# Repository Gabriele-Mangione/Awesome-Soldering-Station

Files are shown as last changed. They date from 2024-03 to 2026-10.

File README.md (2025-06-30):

# ✨ Awesome Soldering Station ✨

---

## Project Overview 💡

This project introduces an **open-source DIY soldering station** featuring **USB-C Power Delivery** and an intuitive **touchscreen interface**. The goal is to provide a very affordable, highly functional, modifiable, and robust soldering solution built with modern embedded technologies for the DIY community!



A key design feature is its compatibility with **jack connector soldering tips**, specifically those used by Weller soldering stations, ensuring broad tip availability and performance.

While the primary development is focused on the **Rust** codebase for the latest iteration, a fully functional C++ version exists on the `2.0` branch, serving as a tested foundation.

---

## Technical Architecture ⚙️

The station's intelligence is distributed across two microcontrollers:

* **ESP32-S3 (Station Mainboard):** This microcontroller drives the core functionality of the station. It's programmed in **Rust** utilizing the `esp-hal` open-source framework. Firmware updates are streamlined and accessible, allowing for easy modification and programming directly through the **USB-C port** used for power delivery.

* **ATtiny24 (Soldering Handle):** A compact microcontroller embedded within the soldering handle, responsible for precise temperature sensing and control. It's programmed in **C++** within the Arduino environment and uploaded via an external ISP.

---

## Hardware Design & Construction 🛠️

The hardware is meticulously designed in **Altium Designer** and comprises two distinct printed circuit boards:

* **Station Mainboard:** This board houses the ESP32-S3, power delivery circuitry, display interface, and other essential components for the station's operation.


* **Soldering Handle Board:** A compact PCB designed to fit within the handle, facilitating sensor integration and handle-specific controls, crucial for the jack connector tips.


These two boards are interconnected by a cable, chosen for both its both comfort and flexibility during use, while ensuring reliable high-current power transmission without impedance issues. (I tested a lot of different ones)

The enclosure for the main station and the handle itself are both **3D printed**. This approach allows for a custom, ergonomic design and simplifies prototyping and production.
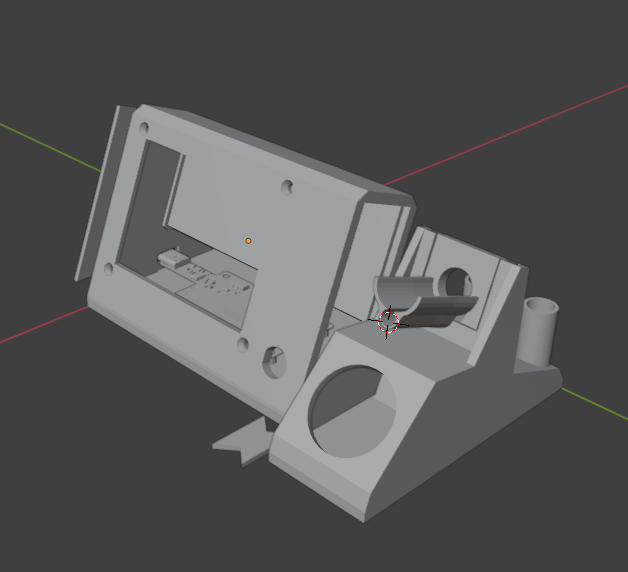
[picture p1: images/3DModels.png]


## Development Status & Technologies Used 💻

* **Hardware Design:** Altium Designer
* **Station Firmware:** Embedded Rust with `esp-hal` (active development branch)
* **Handle Firmware:** C++ using the Arduino environment
* **Case & Handle:** 3D Printed, designed with Blender
* **Tip Compatibility:** Designed for **Weller jack connector soldering tips**

---

## Getting Started (Prerequisites) 📝

#### For the Hardware:
If you take the DIY route:
* Order PCBs from your favourite PCB manufacturer (I use AISLER and JLCPCB)
* Order Parts from my Digi-Key Lists:
    * Handle: https://www.digikey.ch/en/mylists/list/VL3OIYCQ1Z
    * Station: https://www.digikey.ch/en/mylists/list/MW1GWRHM6E
* 3D print the files in the 3D-Models Folder
* Solder and mount everything together!

If you don't have the needed tools, you can opt to buy the finished product directly from me.
If so, feel free to contact me at Gabriele.Mangione@hotmail.com
#### For ESP32-S3 Firmware (Rust):
* **`esp-hal` Toolchain:** Refer to [https://docs.esp-rs.org/book/](https://docs.esp-rs.org/book/) for detailed setup instructions.
    * **Note:** For Windows users, Rust must be installed via `rustup` for compatibility.

* TODO: insert libs

#### For ATtiny24 Firmware (C++):
* **Arduino IDE** or **Arduino CLI**
* Appropriate ATtiny24 board definitions for the Arduino environment.

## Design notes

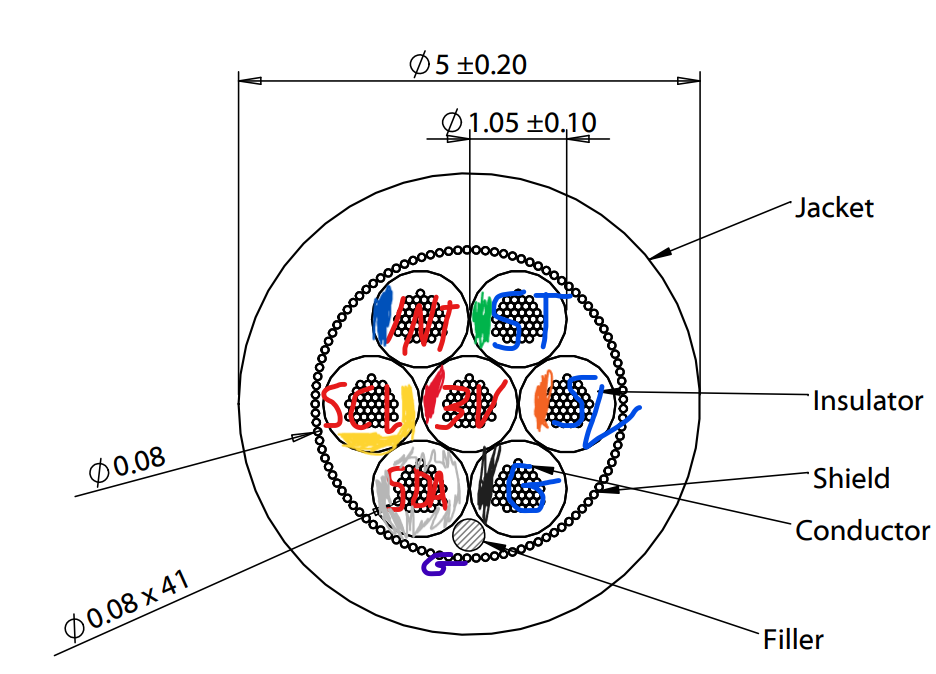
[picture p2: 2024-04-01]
cableorder.png

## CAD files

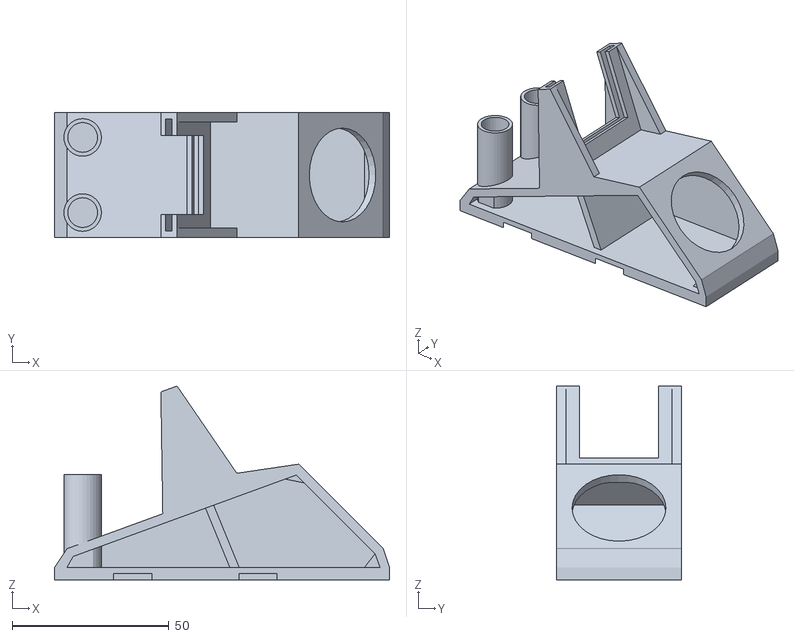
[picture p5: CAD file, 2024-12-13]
3D-Models/Case/iron_holder.stl
107.0 x 40.0 x 62.0

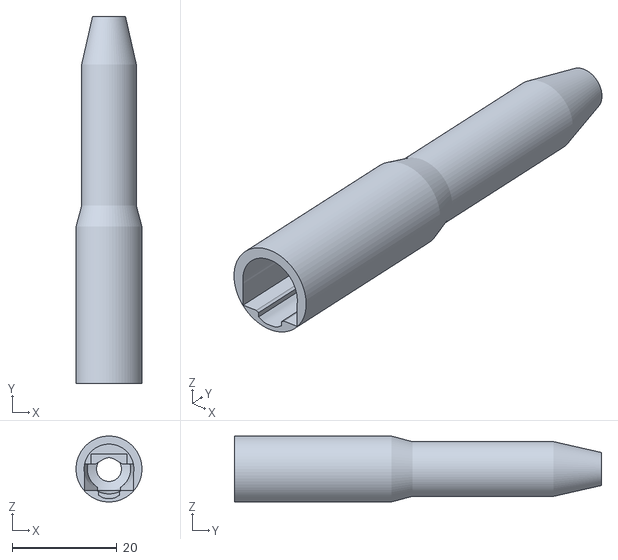
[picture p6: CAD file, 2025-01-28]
3D-Models/Iron-Pen/Iron-pen5.8.stl
12.6 x 70.1 x 12.6

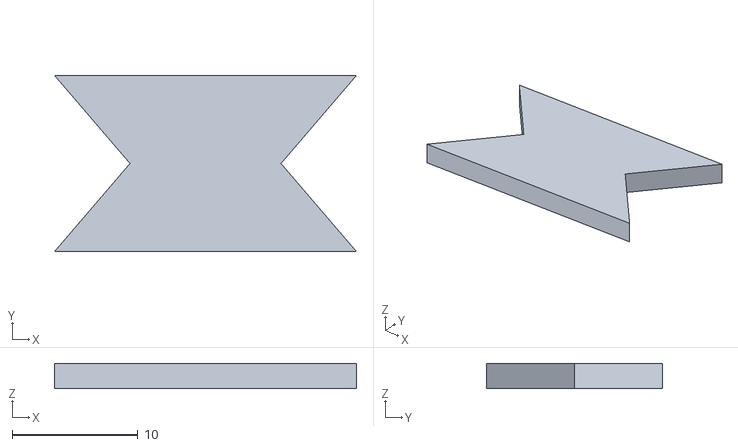
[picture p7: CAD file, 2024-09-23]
3D-Models/Case/connector.stl
24.0 x 14.0 x 2.00

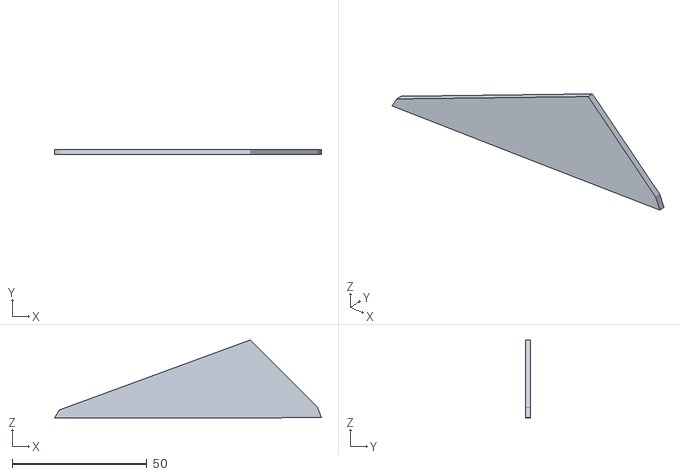
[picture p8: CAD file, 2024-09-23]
3D-Models/Case/iron_holder_wall.stl
98.9 x 2.00 x 28.9

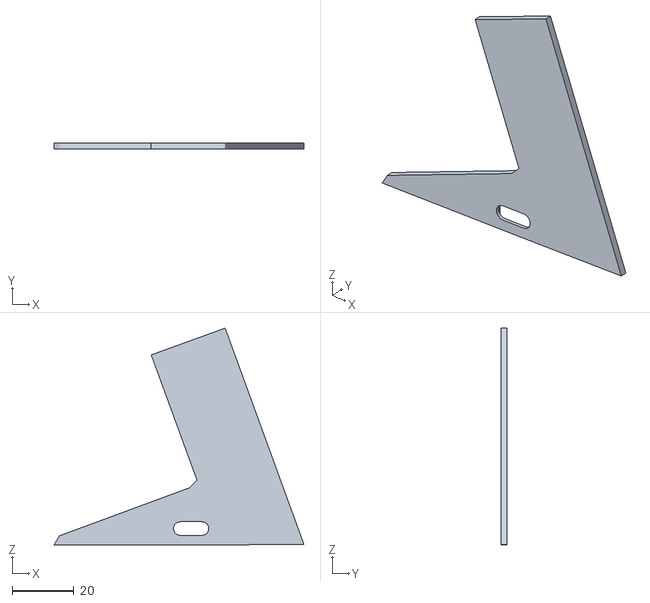
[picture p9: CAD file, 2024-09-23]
3D-Models/Case/usbc_wall.stl
80.9 x 2.00 x 70.2

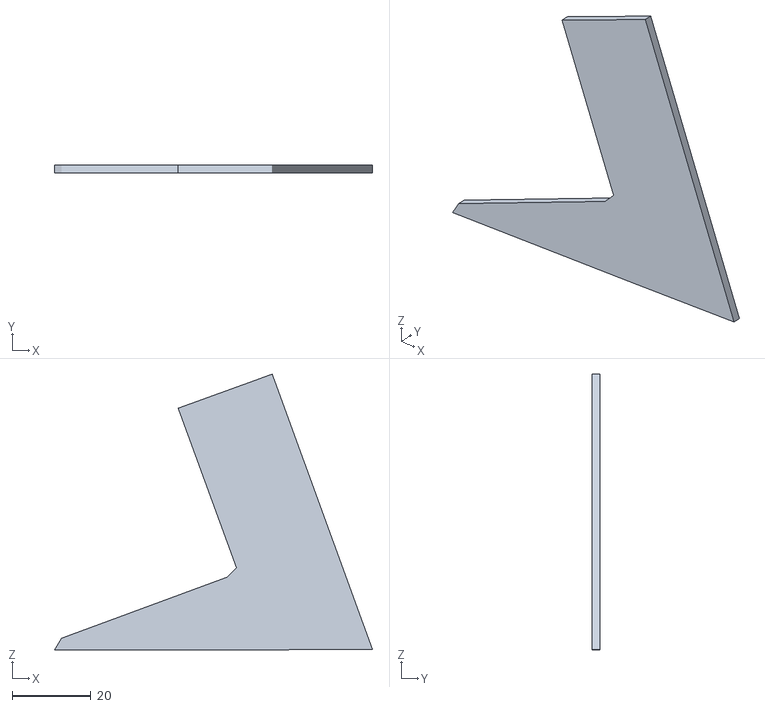
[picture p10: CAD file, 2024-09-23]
3D-Models/Case/normal_wall.stl
80.9 x 2.00 x 70.2

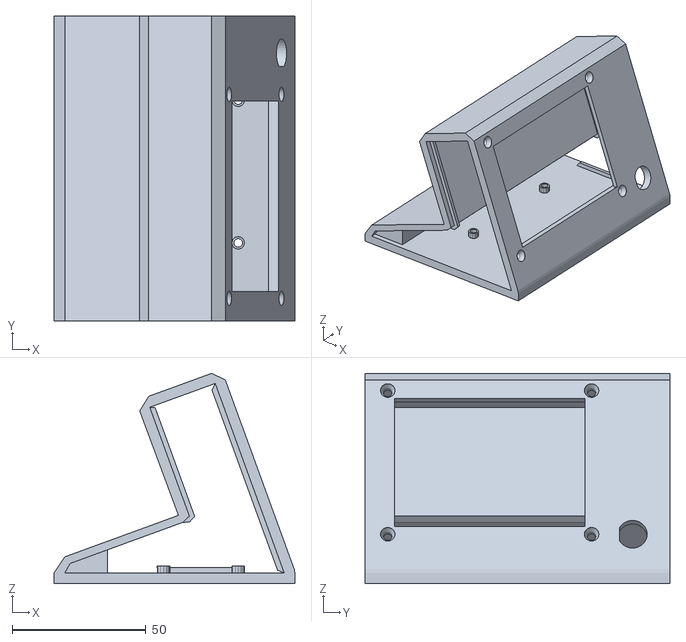
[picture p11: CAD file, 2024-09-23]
3D-Models/Case/station.stl
90.0 x 114.0 x 78.6

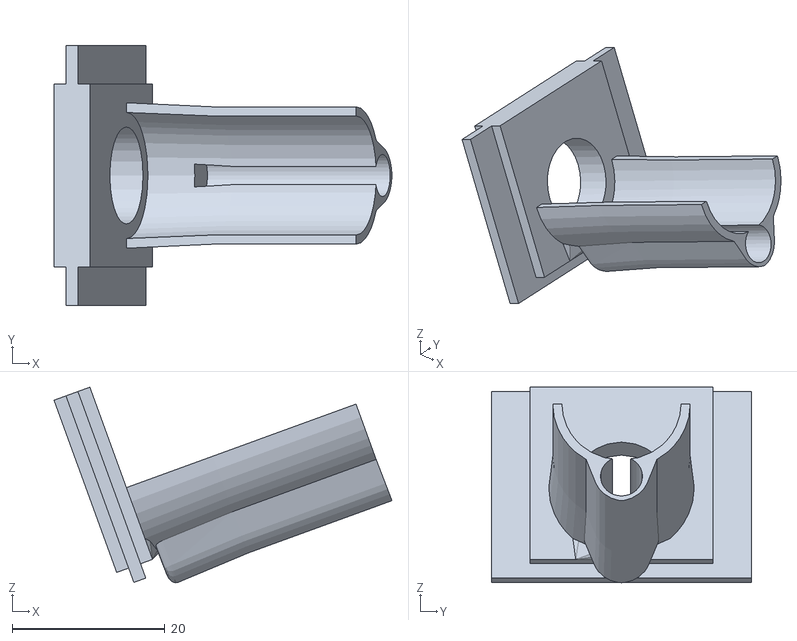
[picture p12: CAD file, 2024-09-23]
3D-Models/Case/iron_slot.stl
44.3 x 34.0 x 25.6

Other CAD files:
3D-Models/Iron-Pen/Iron-pen5.7.stl
3D-Models/Iron-Pen/Iron-pen5.9.stl
3D-Models/Iron-Pen/Iron-pen5.5.stl
3D-Models/Iron-Pen/Iron-pen5.6.stl
3D-Models/Case/station.blend
3D-Models/Iron-Pen/Iron-pen.blend
3D-Models/Iron-Pen/programmer.blend

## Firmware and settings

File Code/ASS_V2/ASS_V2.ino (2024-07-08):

/*
// The ESP32 and TFT the pins used for testing are:
#define TFT_CS   47//33  // Chip select control pin (library pulls permanently low
#define TFT_DC   48 //15  // Data Command control pin - must use a pin in the range 0-31
#define TFT_RST  0 //32  // Reset pin, toggles on startup

#define TFT_WR    43  // Write strobe control pin - must use a pin in the range 0-31
#define TFT_RD    44  // Read strobe control pin

//RST
//Lite
//4 TouchPins

#define TFT_D0   42  // Must use pins in the range 0-31 for the data bus
#define TFT_D1   41  // so a single register write sets/clears all bits.
#define TFT_D2   40 //26  // Pins can be randomly assigned, this does not affect
#define TFT_D3   39 //25  // TFT screen update performance.
#define TFT_D4   38
#define TFT_D5   37
#define TFT_D6   36 //27
#define TFT_D7   35 //14
*/

//TODO check if iron is connected, through i2c ack bit:
//i2c_master_cmd_begin returns ESP_FAIL when not receiving ACK
//Register 56 of mpu must be set to 0x40 for interrupt on motion detection

//TODOOOO implement new TFT_eSPI lib version!!!


#include <SPI.h>
#include <Wire.h>
#include <TFT_eSPI.h>  // Hardware-specific library
#include "TouchBreakout.h"
#include <WiFi.h>
#include <ESPmDNS.h>
#include <WiFiUdp.h>
#include <ArduinoOTA.h>
#include "ringedBuffer.h"
#include "FUSB302.h"
#include "FFat.h"
#include <algorithm>

#define SSID_WIFI "Coldspot"
#define PW_WIFI "Hotstoppassword"

#define YP 1
#define YM 14
#define XP 13
#define XM 2

#define SOLDERTEMP_PIN 8
#define SOLDER_OD 9

TaskHandle_t solderTask;
TaskHandle_t wiFiTask;
TaskHandle_t displayTask;
TaskHandle_t sensorTask;

SemaphoreHandle_t semaphoreMVDT;

const uint8_t INTERRUPT_PIN = 12;
const uint8_t SCL_PIN = 11;
const uint8_t SDA_PIN = 10;

uint16_t goalTemp = 380;
uint16_t actualTemp = 0;
uint32_t standbyTime = 1000;

uint8_t mpuVar = 0;


  uint16_t attached = 0;

  TwoWire i2cMpu(1);

enum DeviceMode {
  RUNNING,
  STANDBY
} deviceMode;

//for adafruit touchscreen library
//TouchScreen ts = TouchScreen(XP, YP, XM, YM, 340); // X+ to X- 340 Ohm
void setup(void) {
  pinMode(0,OUTPUT);
  digitalWrite(0,LOW);
  delay(1000);
  Serial.begin(115200);
  FFat.begin();
  Fusb302::init(5,4,400000);
  xTaskCreatePinnedToCore(solderProcess, "Solder Task", 10000, NULL, 1, &solderTask, 1);
  //xTaskCreatePinnedToCore(wiFiProcess, "WiFi Task", 10000, NULL, 0, &wiFiTask, 0);
  xTaskCreatePinnedToCore(displayProcess, "Display Task", 10000, NULL, 0, &displayTask, 0);
  xTaskCreatePinnedToCore(sensorProcess, "Sensor and MPU Task", 10000, NULL, 0, &sensorTask, 0);
}

class Button {
private:
  uint16_t x;
  uint16_t y;
  uint16_t w;
  uint16_t h;
  uint16_t r;
  uint16_t colour;
  TFT_eSPI* tft = NULL;

public:
  Button(TFT_eSPI* _tft, uint16_t _x, uint16_t _y, uint16_t _w, uint16_t _h, uint16_t _r) {
    tft = _tft;
    x = _x;
    y = _y;
    w = _w;
    h = _h;
    r = _r;
  }

  void setColor(uint16_t _colour) {
    if (colour != _colour) {
      tft->fillRoundRect(x, y, w, h, r, _colour);
      colour = _colour;
    }
  }

  bool isPressed(uint16_t _x, uint16_t _y) {
    return _x > x && _x < (x + w) && _y > y && _y < (y + h);
  }
};

void solderProcess(void* pvParameters) {

  pinMode(SOLDERTEMP_PIN, INPUT);
  pinMode(SOLDER_OD, OUTPUT);


    
//Serial.printf("init, format: %i, mount: %i\n", /*FFat.format()*/0, FFat.begin());

    Serial.printf("Print File!:\n");
    fs::File file = FFat.open("/fusb.txt");
    if(!file){
        Serial.printf("ERROR2, file not present?\n");
        //return;
    }
    uint32_t myAddress = 0;
    while(file.available()){
        uint8_t myData = file.read();
        Serial.write(myData);
        myAddress++;
    }
    file.close();
        Serial.printf("\nFile closed\n");
  RingedBuffer<float, 30> temperatureBuffer;

  while (true) {
    // deactivate Output in order to read the temperature
    digitalWrite(SOLDER_OD, LOW);
    // wait 2 milliseconds to prevent bad measurements from em of switching voltage
    delay(40);
    // read the amplified temperature voltage and convert it into temperature
    temperatureBuffer.push((float)analogRead(SOLDERTEMP_PIN));
    actualTemp = map((uint16_t)temperatureBuffer.avg(), 0, 4095, 20, 600);
    switch (deviceMode) {
      case RUNNING:
        {
          float deltaTemp = std::max(0,goalTemp - actualTemp);
          if (actualTemp < goalTemp) {
          // activate Soldering Iron if goalTemp is not yet reached
            digitalWrite(SOLDER_OD, HIGH);
          }
          delay((uint32_t) (deltaTemp/10.));
          delay(1);
          /*
          if (deltaTemp > 0) {
            delay((uint16_t)deltaTemp /10);
          }
          */
        }
        break;
      case STANDBY:
        {
        }
        break;
      default:
        {
        }
        break;
    }
  }
}

void displayProcess(void* pvParameters) {
  TouchPoint TouchScreen = TouchPoint(XP, YP, XM, YM);

  digitalWrite(0,HIGH);
  TFT_eSPI tft = TFT_eSPI();
  Button AugButton(&tft, 200, 30, 100, 70, 5);
  Button DecButton(&tft, 200, 140, 100, 70, 5);

  tft.init();
  tft.setRotation(1);
  tft.setTextSize(3);

  //tft.fillScreen(TFT_BLACK);
  //tft.fillScreen(TFT_RED);
  //tft.fillScreen(TFT_GREEN);
  //tft.fillScreen(TFT_BLUE);
  //tft.fillScreen(TFT_BLACK);
  tft.fillScreen(TFT_BLACK);

  unsigned long blinkTimer = 0;

  while (true) {
    unsigned long loopTime = millis();
    blinkTimer = loopTime - (loopTime%500);
    //equivalent but branch
    /*if (loopTime - blinkTimer > 500) {
      blinkTimer = loopTime;
    }
    */

    switch (deviceMode) {
      case RUNNING:
        {
          static unsigned long lastSecond = 0;
          if (loopTime / 1000 != lastSecond) {
            lastSecond = loopTime / 1000;
            standbyTime--;
          }
          if (standbyTime < 1) {
            deviceMode = DeviceMode::STANDBY;
          }
        }
        break;
      case STANDBY:
        {
        }
        break;
      default:
        {
        }
        break;
    }

    //touchscreen part
    uint16_t x = map(TouchScreen.getX(), 4000, 500, 0, 320);
    uint16_t y = map(TouchScreen.getY(), 500, 3800, 0, 240);

    x = x > 320 ? 0 : x;
    y = y > 240 ? 0 : y;

    if (AugButton.isPressed(x, y)) {
      AugButton.setColor(0xDFE0);
      goalTemp++;
    } else {
      AugButton.setColor(TFT_GREEN);
    }

    if (DecButton.isPressed(x, y)) {
      DecButton.setColor(0xFA80);
      goalTemp--;
    } else {
      DecButton.setColor(TFT_RED);
    }

    tft.setCursor(0, 10);
    tft.setTextColor(0xFFFF, 0x0000);
    tft.printf("Set   Temp:\n");
    tft.setTextSize(5);
    tft.printf("%3i C\n", goalTemp);
    tft.setTextSize(3);
    tft.printf("Meas. Temp:\n");
    tft.setTextSize(5);
    tft.printf("%3i C\n", actualTemp);
    tft.setTextSize(3);
    if (deviceMode == DeviceMode::STANDBY && loopTime - blinkTimer < 250) {
      tft.setTextColor(0x841F, 0x0000);
      tft.printf("STANDBY");
      tft.setTextColor(0xFFFF, 0x0000);
    } else {
      tft.printf("       ");
    }

    tft.setCursor(0, 186);
    tft.printf("MPUstate: %i", mpuVar);

    tft.setCursor(0, 216);
    tft.printf("timer: %3i", standbyTime);
    delay(10);
  }
}

bool mpuInitMVDT() {
//create new i2c driver
  i2cMpu.begin(SDA_PIN, SCL_PIN, 5000);
  delay(1);
  //set to standby
  i2cMpu.beginTransmission(0x4C);
  i2cMpu.write(0x07);
  i2cMpu.write(0x00);
  if (i2cMpu.endTransmission())
    return true;
  //interrupt masking
  i2cMpu.beginTransmission(0x4C);
  i2cMpu.write(0x06);
  i2cMpu.write(0x04);
  if (i2cMpu.endTransmission())
    return true;
  //set range and scale 
  i2cMpu.beginTransmission(0x4C);
  i2cMpu.write(0x20);
  i2cMpu.write(0x09);
  if (i2cMpu.endTransmission())
    return true;
  //set samplerate to max
  /*
  i2cMpu.beginTransmission(0x4C);
  i2cMpu.write(0x08);
  i2cMpu.write(0x05);
  if (i2cMpu.endTransmission())
    return true;
    */
  //activate Anymotion
  i2cMpu.beginTransmission(0x4C);
  i2cMpu.write(0x09);
  i2cMpu.write(0x04);
  if (i2cMpu.endTransmission())
    return true;
  //set Anymotion Threshold and debounce
  i2cMpu.beginTransmission(0x4C);
  i2cMpu.write(0x43);
  //15 bit threshold
  i2cMpu.write(0x1A);
  i2cMpu.write(0x00);
  //debounce
  i2cMpu.write(0x03);
  if (i2cMpu.endTransmission())
    return true;
  //set to wake (no more register writing from here on)
  i2cMpu.beginTransmission(0x4C);
  i2cMpu.write(0x07);
  i2cMpu.write(0x01);
  if (i2cMpu.endTransmission())
    return true;

  return false;
}

void IRAM_ATTR movementDetectionISR() {
  xSemaphoreGiveFromISR(semaphoreMVDT, NULL);
}

void sensorProcess(void* pvParameters) {
  pinMode(INTERRUPT_PIN, INPUT_PULLUP);
  //attachInterrupt(INTERRUPT_PIN, movementDetectionISR, FALLING);
  //semaphoreMVDT = xSemaphoreCreateBinary();
  mpuVar = 1;
  while (mpuInitMVDT()){
      delay(10);
  }
  delay(10);
  mpuVar = 3;

  while (true) {
    //xSemaphoreTake(semaphoreMVDT, portMAX_DELAY);
    mpuVar = 4;
    //read interrupt status register to be sure MPU is connected and right interrupt is triggered
    i2cMpu.beginTransmission(0x4C);
    i2cMpu.write(0x13);
    i2cMpu.endTransmission();
    i2cMpu.requestFrom(0x4C, 1);
    unsigned long currentTime = millis();
    //while (!i2cMpu.available() && (millis() - currentTime < 100));
        //timeout after 100ms
    while(i2cMpu.available()){
        if (i2cMpu.read() & 0x04) {
        //Motion detected
        deviceMode = DeviceMode::RUNNING;
        standbyTime = 1000;
        }
    }
    delay(100);

  }
}

void loop() {}

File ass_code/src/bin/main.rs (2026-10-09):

#![no_std]
#![no_main]

extern crate alloc;
use core::cell::RefCell;
use core::cmp::min;
use core::default;

use alloc::vec::Vec;
use alloc::{format, vec};
use critical_section::Mutex;
use embassy_executor::Spawner;
use embassy_sync::blocking_mutex::raw::{CriticalSectionRawMutex, NoopRawMutex};
use embassy_sync::channel::Channel;
use embassy_sync::signal::Signal;
use embassy_time::{Duration, Instant, Timer, WithTimeout};
use embedded_graphics::mono_font::ascii::FONT_10X20;
use embedded_graphics::mono_font::MonoTextStyle;
use embedded_graphics::prelude::{Point, Size};
use embedded_graphics::primitives::{Circle, Primitive, Rectangle, StyledDrawable};
use embedded_graphics::primitives::{Line, PrimitiveStyle};
use embedded_graphics::text::renderer::CharacterStyle;
use embedded_graphics::text::Text;
use esp_backtrace as _;
use esp_hal::clock::CpuClock;
use esp_hal::gpio::{AnyPin, Input, Io, Level, Output};
use esp_hal::i2c::master::AnyI2c;
use esp_hal::peripherals::{self, IO_MUX};
use esp_hal::timer::timg::TimerGroup;
use esp_storage::FlashStorage;

use ass_code::soldering::{Soldering, TempData};
use ass_code::touchbreakout_cap::{Touch, TouchBreakoutCap, TouchEventFlag};
use ass_code::{fusb302, soldering};
use ass_code::{ili9341, MyColor};
use embedded_graphics::{self, Drawable, Pixel};
use log::{info, warn};
use ringbuffer::{ConstGenericRingBuffer, RingBuffer};

//static mut APP_CORE_STACK: Stack<8192> = Stack::new();

#[esp_hal_embassy::main]
async fn main(spawner: Spawner) {
    // generator version: 0.2.2
    let config = esp_hal::Config::default().with_cpu_clock(CpuClock::max());
    let peripherals = esp_hal::init(config);
    esp_println::logger::init_logger_from_env();

    esp_alloc::heap_allocator!(72 * 1024);

    let timg0 = TimerGroup::new(peripherals.TIMG0);
    esp_hal_embassy::init(timg0.timer0);

    // init fusb, select 9 volt
    let pdo_vec: Vec<fusb302::PDO>;

    let mut pdo_requested = false;
    //log::info!("init fusb!");
    let mut fusb = fusb302::Fusb::new(
        peripherals.GPIO5.into(),
        peripherals.GPIO4.into(),
        peripherals.I2C0,
        0x22,
    );
    //log::info!("scan pds!");
    pdo_vec = fusb.scan_pds().await.unwrap();
    if pdo_vec.len() > 0 {
        let found_pdo = pdo_vec.iter().find(|&&x| x.voltage == 9000);
        if found_pdo.is_some() {
            fusb.request_pdo(*found_pdo.unwrap(), 3000, 3000).unwrap();
            pdo_requested = true;
        }
    }
    log::info!("request pdo!");

    //for some reason necessary when using reg write for pins. DON'T DELETE
    Output::new(peripherals.GPIO35, Level::Low);
    Output::new(peripherals.GPIO36, Level::Low);
    Output::new(peripherals.GPIO37, Level::Low);
    Output::new(peripherals.GPIO38, Level::Low);
    Output::new(peripherals.GPIO39, Level::Low);
    Output::new(peripherals.GPIO40, Level::Low);
    Output::new(peripherals.GPIO41, Level::Low);
    Output::new(peripherals.GPIO42, Level::Low);
    Output::new(peripherals.GPIO43, Level::Low);
    Output::new(peripherals.GPIO44, Level::Low);
    Output::new(peripherals.GPIO47, Level::Low);
    Output::new(peripherals.GPIO48, Level::Low);

    //init screen
    let mut screen = ili9341::ILI9341::new();

    let mut style = MonoTextStyle::new(&FONT_10X20, ass_code::MyColor(255, 255));
    style.set_background_color(Some(ass_code::MyColor(0, 0)));

    //draw black screen
    Rectangle::new(Point::new(0, 0), Size::new(320, 240))
        .into_styled(PrimitiveStyle::with_fill(ass_code::MyColor(0, 0)))
        .draw(&mut screen)
        .unwrap();

    //print pdo info to screen
    if pdo_requested == true {
        Text::new("A PDO has been requested", Point::new(50, 170), style)
            .draw(&mut screen)
            .unwrap();
    }
    let pdo_info = format!("pdo amount: {}", pdo_vec.len());
    Text::new(&pdo_info, Point::new(50, 75), style)
        .draw(&mut screen)
        .unwrap();
    for pdo in pdo_vec {
        log::info!("print pdo");
        let s = format!("V: {}, I: {}, id: {}", pdo.voltage, pdo.current, pdo.id);
        Text::new(&s, Point::new(50, 110 + pdo.id as i32 * 25), style)
            .draw(&mut screen)
            .unwrap();
    }

    //developing handle code
    /*
    let rx_gyro = Input::new(peripherals.GPIO12, esp_hal::gpio::Pull::Down);
    let mut red_style = MonoTextStyle::new(&FONT_10X20, ass_code::MyColor(255, 0));
    red_style.set_background_color(Some(ass_code::MyColor(0, 0)));
    let mut time = 0;

    loop {
        if rxGyro.is_high() {
            time = 500;
        } else if time >= 0 {
            time -= 1;
        }

        if time > 0 {
            let st = format!("Movement {}", time);
            Text::new(&st, Point::new(50, 180), style)
                .draw(&mut screen)
                .unwrap();
        } else if time == 0 {
            Text::new("no Movement      ", Point::new(50, 180), red_style)
                .draw(&mut screen)
                .unwrap();
        }
    }
    */

    log::info!("init soldering!");
    static mut CHAN: Channel<NoopRawMutex, TempData, 3> =
        Channel::<NoopRawMutex, TempData, 3>::new();

    let flash = FlashStorage::new();
    let soldering = Soldering::new(
        peripherals.GPIO11.into(),
        peripherals.GPIO12.into(),
        peripherals.GPIO9.into(),
        peripherals.GPIO8,
        peripherals.UART0.into(),
        peripherals.ADC1,
        peripherals.LEDC,
        flash,
        unsafe { CHAN.sender() },
    );

    spawner.spawn(soldering.task()).unwrap();

    log::info!("init touch!");
    let ts_sda = peripherals.GPIO14;
    let ts_scl = peripherals.GPIO13;
    let ts_irq = peripherals.GPIO1;
    /*spawner
        .spawn(handle_touch_events(
            ts_sda.into(),
            ts_scl.into(),
            ts_irq.into(),
            peripherals.IO_MUX,
            peripherals.I2C1.into(),
        ))
        .unwrap();
    */

    //touch circles
    //let mut balls: Vec<Circle> = vec![];
    let mut styles = vec![];
    styles.push(PrimitiveStyle::with_fill(ass_code::MyColor(0xF8, 0)));
    styles.push(PrimitiveStyle::with_fill(ass_code::MyColor(0xE0, 0)));
    styles.push(PrimitiveStyle::with_fill(ass_code::MyColor(0xD0, 0)));
    styles.push(PrimitiveStyle::with_fill(ass_code::MyColor(0xC0, 0)));
    styles.push(PrimitiveStyle::with_fill(ass_code::MyColor(0xB0, 0)));
    styles.push(PrimitiveStyle::with_fill(ass_code::MyColor(0x90, 0)));
    styles.push(PrimitiveStyle::with_fill(ass_code::MyColor(0x70, 0)));
    styles.push(PrimitiveStyle::with_fill(ass_code::MyColor(0x50, 0)));
    styles.push(PrimitiveStyle::with_fill(ass_code::MyColor(0x30, 0)));
    styles.push(PrimitiveStyle::with_fill(ass_code::MyColor(0x10, 0)));

    let mut rb = ConstGenericRingBuffer::<Circle, 10>::new();
    let mut diagram_data = ConstGenericRingBuffer::<(u8, u8, u8, u8), 276>::new();
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

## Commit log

2022-06-28 minor update
    solder pin switched to 7
2023-06-02 displaying working buttons and touch coordinates
2023-06-14 fix max temp problem (uint8_t vs uint16_t) & more
    [ASS_V2.ino, TouchBreakout.cpp]
2023-12-26 added 3d model for handle
    [Iron-pen.blend, Iron-penp1.stl, Iron-penp2.stl]
2023-12-26 designed case
    [Iron-pen.blend, case.stl, untitled.blend]
2024-02-14 Added Sensor detection code
2024-02-14 note added for bug fix
    [ASS_V2.ino]
2024-02-15 added standby mode with movement detection
    [ironholder.stl, untitled.blend]
2024-03-21 added image for cable
2024-03-27 added models
    [Iron-pen.blend, casev2.stl, casev57.stl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]
2024-03-27 new pen models
    [Iron-pen.blend, Iron-penclosingv2.2.stl, Iron-penclosingv2.3.stl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]
2024-04-02 modified side of model
    [sideusbc2.stl, untitled.blend]
2024-04-14 changed to new accelerometer
2024-07-08 added 3d models and first version of attinyhandle
    [Iron-pen.blend, Iron-pen3.stl, Iron-penclosingv3.stl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]
2024-08-28 restructured directories
    [Iron-pen.blend, Iron-pen3.stl, Iron-penclosingv2.2.stl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]
2024-09-23 3d model stuff
    [Iron-pen.blend, Iron-pennewwwclose.stl, Iron-pennewwwstl.stl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]
2024-09-23 changed structure and continued with the touchscreen driver
2024-10-26 saving point
    [Iron-pen.blend, Iron-penv5.1.stl, Iron-penv5.2.stl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]
2024-10-27 added new 3d pen variant
    [Iron-pen.blend, Iron-pen5.3.stl]
2024-11-07 idea to try for fixing pin register activation
    [ili9341.rs]
2024-11-07 added magnetic sensor slot to pen 3d model
    [Iron-pen.blend, Iron-pen5.4.stl]
2024-11-19 ili driver stuff
2024-11-20 fixed enable register write number to fit with pins
    [ili9341.rs]
2024-11-20 this is bs. no clue why the pins don't work if no pin driver is created first
2024-11-21 commenting unused stuff (to fix yet)
    [ili9341.rs]
2024-11-24 cleaned code, solved pin problem in ili driver (pin must be reset before operating) and runs whole black screen in 20 ms
    [fusb302.rs, ili9341.rs, main.rs]
2024-12-04 reorganised 3d-model files
    [Iron-pen3.stl, Iron-pen5.3.stl, Iron-penclosingv2.2.stl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]
2024-12-06 exported missing last 3d model
    [iron_slot.stl]
2024-12-13 removed double wall in ironholder
    [iron_holder.stl, station.blend]
2024-12-17 touchscreen works now (orange screen is broken) and implemented touch trace
    [main.rs]
2025-01-13 made first botch of pressure reading
2025-01-22 continued with solder_process
2025-01-23 async stuff (doesn't work)
    [main.rs]
2025-01-23 testing solder task without multiprocessing
2025-01-28 updated pen model
    [Iron-pen.blend, Iron-pen5.5.stl, Iron-pen5.6.stl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]
2025-01-31 changed read_oneshot to read_blocking. Readings don't crash anymore
    [main.rs]
2025-01-31 integrated a simulation for the pid controller
2025-04-16 fixed interrupts in attinyhandle, made a visual help in the station code to develop attinyhandle
    TODO:
    RMT detection in handle.
    Differential one wire / uart (to decide) with communication protocol.
    further develop station code
    [attinyhandle.ino, main.rs]
2025-06-20 added soldering file
2025-07-06 esp interrupt logic and protocol
2025-07-10 added signals for interrupt and touch point communication
2025-07-16 integrated soldering file. Added ringbuffer
2025-07-27 send data from soldering process to display
2025-08-25 Drawing PID on screen
2025-08-26 uart communication start, introduced timout in graph drawing
2025-09-02 removed prints, diagram now erases only used pixels in frame, instead of fully drawing a black square
2025-09-04 scrolling was fixed to 1, essentially not scrolling. TO TEST
    [main.rs]
2025-09-05 fixed overwriting of last diagram frame and touching red circles
    [main.rs]
2025-09-16 separation of uart communication with handle
2026-05-30 made it compile and clamped diagram draw values
2026-05-31 fixed fusb pdo request, color code, delay time measuring and tested pwm out
    [attinyhandle.ino, fusb302.rs, main.rs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]
2026-10-09 added wait timer after setting pwm out so tip can heat up, changed temp ref values and removed unused delay
2026-10-12 fixed adc reading, adjusted pid, changed measuring frequency
